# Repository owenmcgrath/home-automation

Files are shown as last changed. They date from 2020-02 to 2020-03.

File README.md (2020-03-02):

# home-automation

**Home Automation**

Welcome to my implementation of connected home automation devices. The goal is to have:
- Various home automation devices (such as automated thermostats, automated lighting, home monitoring systems etc.)
- A server that drives communication between the devices and the outside world
- Applications for Command/Control from the outside world (android app, web portal)

Here are my requirements
- Devices must have both physical controls and IOT remote controls
- Everything must have a backup plan. (in case of no internet, no power)
- Software must be scalable for ease of additions of new devices and configurability
- Interfaces must be modern both physically and in software (no hacky electronics, bad UI)

In Progress
- Dual Control thermostat
- Server

To Do
- Android Application C2 Interface, with scheduling and monitoring
- Remote light switch
- Home network modifications

Maybes
- Motion aware/tracking device
- Automated outdoor spicket control (gardening etc)
- Enhanced energy usage & monitoring
- Machine learning

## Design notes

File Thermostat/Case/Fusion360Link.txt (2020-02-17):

The drawings for the case are located here:

https://a360.co/322cvkj

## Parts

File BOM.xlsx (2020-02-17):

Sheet: Thermostat
ITEM | QTY | COST | LINK
Tolako 5V relay | 1 | $1.04 | https://www.amazon.com/Tolako-Arduino-Indicator-Channel-Official/dp/B00VRUAHLE/
Raspberry Pi Zero | 1 | $10 | https://www.adafruit.com/product/3400
DHT-22 and 10k Resistor | 1 | $9.95 | https://www.adafruit.com/product/385
Panel Mount 1k potentiometer | 1 | $0.95 | https://www.adafruit.com/product/1789
Monochrome OLED |  | $19.50 | https://www.adafruit.com/product/326
Micro SD Card | 1 | $6.49 | https://www.amazon.com/SanDisk%C2%AE-microSDHCTM-8GB-Memory-Card/dp/B0012Y2LLE/
 | TOTAL | $47.93

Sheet: Case
Case printed at Sculpteo: | $23.41

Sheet: Server
ITEM | QTY | COST | LINK
Anything that can connect to a network and run python | 1

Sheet: MISC
ITEM | QTY | COST | NOTES | LINK
Breadboard Kit | 1 | 9.99 | For testing | https://www.amazon.com/Standard-Jumper-Solderless-Prototype-Breadboard/dp/B07H7V1X7Y/
Soldering Iron Kit | 1 | 10.98 |  | https://www.amazon.com/Soldering-Iron-Kit-Temperature-Rarlight/dp/B07PDK3MX1?s=hi
Soldering Helping Hands | 1 | 7.2 |  | https://www.amazon.com/ProsKit-900-015-Helping-Hands-Soldering/dp/B01E62773K
USB SD Card Reader | 1 | 7.99 | For burning pi images | https://www.amazon.com/UGREEN-Reader-Portable-Adapter-Windows/dp/B0779V61XB/
Hot Glue Gun | 1 | 10.99 | For glueing pi and oled onto case | https://www.amazon.com/ccbetter-Upgraded-Removable-Anti-hot-Flexible/dp/B01178RVI2/
 | Total | 47.15

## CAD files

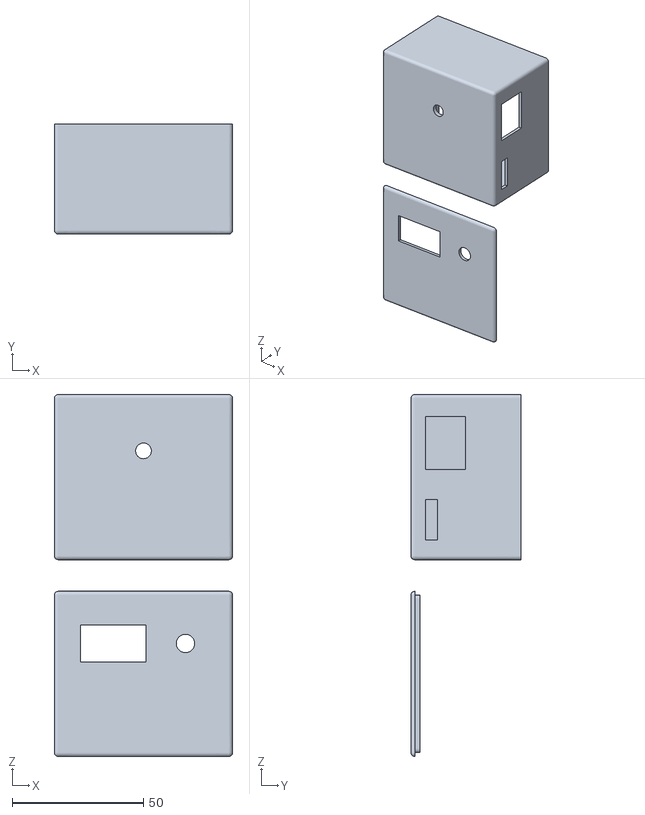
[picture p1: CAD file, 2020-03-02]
Thermostat/Case/Thermostat enlarged.stl
68.0 x 42.0 x 138.0

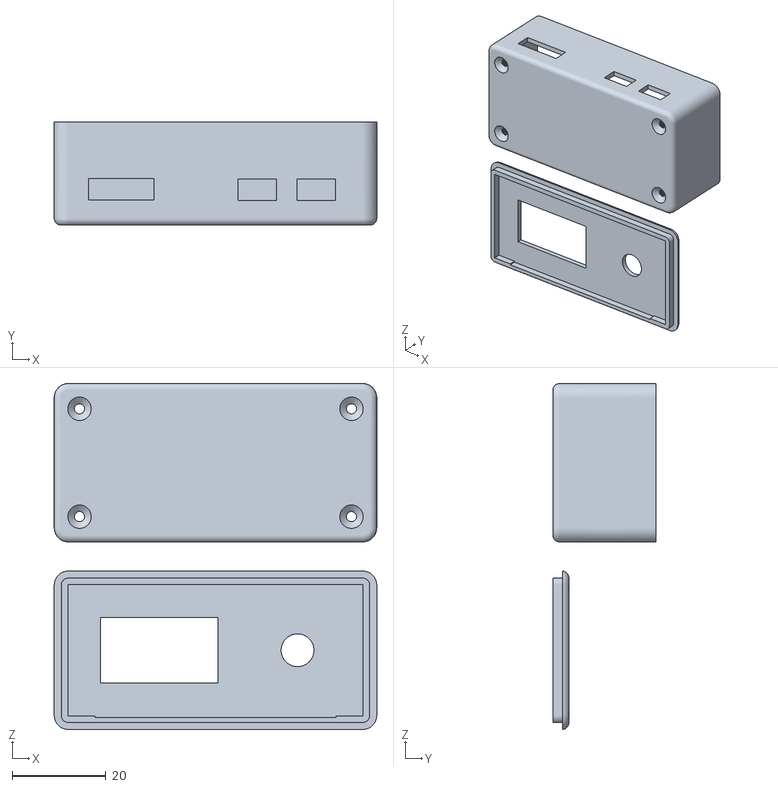
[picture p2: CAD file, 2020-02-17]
Thermostat/Case/thermostat.stl
68.8 x 22.0 x 73.8

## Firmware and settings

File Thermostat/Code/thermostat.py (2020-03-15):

import board
import digitalio
from PIL import Image, ImageDraw, ImageFont
import adafruit_ssd1306
import Adafruit_DHT
import RPi.GPIO as GPIO
import time

def UpdateOledDisplay(oled, font, draw, image, setting, temp):
	# Clear the image
	draw.rectangle((0, 0, oled.width, oled.height), outline = 0, fill = 0)
	# Draw the text
	text = "Room Temp: " + str(round(temp, 1)) + " *F"
	text2 = "Setting: " + str(setting) + " *F"

	(font_width, font_height) = font.getsize(text)
	draw.text((oled.width//2 - font_width//2, 3*oled.height//4 - font_height//2),
          text2, font=font, fill=255)

	draw.text((oled.width//2 - font_width//2, oled.height//4 - font_height//2), text, font = font, fill = 255)

	# Display image
	oled.image(image)
	oled.show()

def GetTemp(dhtSensor, dhtPin):
	humidity, temperature = Adafruit_DHT.read_retry(dhtSensor, dhtPin)
	if(temperature is None):
		temperature = -1 #Theres an error likely with the wiring
	return 1.8 * temperature + 32



if __name__ == "__main__":

	"""
	OLED CONFIG
	"""
	# Define the Reset Pin
	oled_reset = digitalio.DigitalInOut(board.D4)

	# Change these
	# to the right size for your display!
	WIDTH = 128
	HEIGHT = 32     # Change to 64 if needed

	# Use for I2C.
	i2c = board.I2C()
	oled = adafruit_ssd1306.SSD1306_I2C(WIDTH, HEIGHT, i2c, addr=0x3d, reset=oled_reset)

	oled.fill(0)
	oled.show()

	image = Image.new('1', (oled.width,oled.height))
	draw = ImageDraw.Draw(image)
	draw.rectangle((0,0,oled.width,oled.height), outline = 0, fill = 0)
	font = ImageFont.load_default()

	"""
	DHT22 CONFIG
	"""
	DHT_SENSOR = Adafruit_DHT.DHT22
	DHT_PIN = 23

	"""
	BUTTON CONFIG
	"""
	UP_BUTTON_PIN = 27
	DOWN_BUTTON_PIN = 22

	GPIO.setwarnings(False)
	GPIO.setup(UP_BUTTON_PIN, GPIO.IN, pull_up_down=GPIO.PUD_DOWN)
	GPIO.setup(DOWN_BUTTON_PIN, GPIO.IN, pull_up_down=GPIO.PUD_DOWN)

	"""
	RELAY CONFIG
	"""
	RELAY_PIN = 17
	GPIO.setup(RELAY_PIN, GPIO.OUT)

	"""
	RUN THE THERMOSTAT!
	"""
	currSetting = 75
	currTemp = GetTemp(DHT_SENSOR, DHT_PIN)
	lastDownButtonState = False
	lastUpButtonState = False
	lineOpen = False
	firstRun = True
	lastLoopTime = 0
	lastSetTime = 0
	while True:
		#get the button input and update the current thermostat setting based on that
		upButtonState = GPIO.input(UP_BUTTON_PIN) == GPIO.HIGH
		downButtonState = GPIO.input(DOWN_BUTTON_PIN) == GPIO.HIGH
		timestamp = time.time()
		if (not lastDownButtonState) and downButtonState:
			currSetting = currSetting - 1
			UpdateOledDisplay(oled, font, draw, image, currSetting, currTemp)
			lastSetTime = timestamp
		if (not lastUpButtonState) and  upButtonState:
			currSetting = currSetting + 1
			print(currSetting)
			UpdateOledDisplay(oled, font, draw, image, currSetting, currTemp)
			lastSetTime = timestamp
		lastUpButtonState = upButtonState
		lastDownButtonState = downButtonState
		noInput = (timestamp - lastSetTime) > 5
		if (lineOpen != (currTemp < currSetting)) or firstRun:
			lineOpen = currTemp < currSetting
			GPIO.output(RELAY_PIN, GPIO.HIGH if lineOpen else GPIO.LOW)
			firstRun = False
		if (timestamp - lastLoopTime) > 30 and noInput:
			lastLoopTime = timestamp
			currTemp = GetTemp(DHT_SENSOR, DHT_PIN)
			UpdateOledDisplay(oled, font, draw, image, currSetting, currTemp)

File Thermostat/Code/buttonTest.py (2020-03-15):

import RPi.GPIO as GPIO

GPIO.setwarnings(False)
GPIO.setmode(GPIO.BOARD)
GPIO.setup(13, GPIO.IN, pull_up_down=GPIO.PUD_DOWN)
GPIO.setup(15, GPIO.IN, pull_up_down=GPIO.PUD_DOWN)

lastDownButtonState = False
lastUpButtonState = False

while True:
	upButtonState = GPIO.input(13) == GPIO.HIGH
	downButtonState = GPIO.input(15) == GPIO.HIGH
	if (not lastDownButtonState) and downButtonState:
		print("Down Button Pushed")
	if (not lastUpButtonState) and  upButtonState:
		print("Up Button Pushed")
	lastUpButtonState = upButtonState
	lastDownButtonState = downButtonState

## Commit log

2020-02-17 Initial Commit
    -Picked parts with the requirements: must have both physical and IOT control
    -Added Bill of materials for all parts
    -Forked Adafruit's version of the Raspberry PI Zero case and
    -Drew Fritzing Wiring Diagrams
    -Bought parts
    [BOM.xlsx, Thermostat.fzz, Zero enclosure v12 v1.stl]
2020-03-02 Added code for testing hardware -blinkatest.py Testing I2C and SPI libraries -dht22test.py Testing DHT22 Temp and Humidity Sensor Libraries -ssd1306_pillow_demo.py Testing Oled Display
2020-03-02 New Thermostat Case
    Added new Thermostat case drawings
    [Thermostat enlarged.stl, thermostat.stl]
2020-03-02 Update Thermostat enlarged.stl
    [Thermostat enlarged.stl]
2020-03-09 Server Code and hardware update
    Changed hardware to use multiple buttons and the Adafruit featherwing relay. Began to write server code
    [Thermostat.fzz]
2020-03-15 -Added test script for the relay and the buttons
2020-03-15 Updated Wiring Diagram
    Updated wiring diagram to switch to normally open
    [Thermostat.fzz]
2020-03-15 Fixed various thermostat bugs Thermostat now fully operational minus networking
    [thermostat.py]
2020-03-16 Server Updates
    Added broadcaster to HOMEIO
    Updated wiring diagram
    Added message flow to text document
    TODO asyncore is not what I thought it was, need to use non-blocking sockets instead of multithreading
    [Thermostat.fzz]
2020-09-27 Async Socket Updates
